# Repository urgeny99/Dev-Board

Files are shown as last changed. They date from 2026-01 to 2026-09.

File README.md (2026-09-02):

# This is a self made dev board that i can use on many different projects. For example mount it on a bread board and connect a small screen or something like that.
# Story
I made started this project without knowing almost anything about PCBs but with the time as i followed the tutrial more and more things got clear. I was not sure what to use this for but i started watching videos and and did research. It is actually a very cool project. I am not sure if it will be easy soldering at home but i like a challange so i'll try it.
I will probably be using this dev board with bread boards to try experimenting and i maybe order some more cool components to try out how they work. (e.g OLED screens, small sensors etc.)
## Parts
What this board has are:
- USB-C conmector
- 16Mb flash storage
- RP2040 "CPU"
- 12MHz Crystal Osillator
- Temperature sensor
- Small NeoPixel
- 20+ GPIO pins






## Based on @KaiTheJollyGuy’s tutorial on how to make a devboard

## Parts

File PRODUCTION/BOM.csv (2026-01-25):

Index | LCSC# | MPN | Manufacturer | Package | Customer # | Description | RoHS | Quantity | MOQ | Multiple | Unit Price($) | Extended Price($)
1 | C15849 | CL10A105KB8NNNC | Samsung Electro-Mechanics | 0603 |  | 1uF ±10% 50V Ceramic Capacitor X5R 0603 | yes | 50 | 50 | 50 | 0.0056 | 0.28
2 | C14663 | CC0603KRX7R9BB104 | YAGEO | 0603 |  | 100nF ±10% 50V Ceramic Capacitor X7R 0603 | yes | 200 | 100 | 100 | 0.0021 | 0.42
3 | C440198 | GRM21BR61H106KE43L | muRata | 0805 |  | 10uF ±10% 50V Ceramic Capacitor X5R 0805 | yes | 20 | 10 | 10 | 0.0628 | 1.26
4 | C1663 | CL10C330JB8NNNC | Samsung Electro-Mechanics | 0603 |  | 33pF ±5% 50V Ceramic Capacitor C0G 0603 | yes | 100 | 100 | 100 | 0.0043 | 0.43
5 | C19702 | CL10A106KP8NNNC | Samsung Electro-Mechanics | 0603 |  | 10uF ±10% 10V Ceramic Capacitor X5R 0603 | yes | 50 | 50 | 50 | 0.0065 | 0.33
6 | C5149201 | SK6812MINI-E | OPSCO Optoelectronics | SMD |  | SMD LED Addressable, Specialty RoHS | yes | 10 | 5 | 5 | 0.0874 | 0.87
7 | C165948 | TYPE-C-31-M-12 | Korean Hroparts Elec | SMD |  | USB-C (USB TYPE-C) Receptacle Connector 16 Position Surface Mount | yes | 10 | 5 | 5 | 0.1789 | 1.79
8 | C50981 | 2.54-1*20P | BOOMELE(Boom Precision Elec) | Through Hole,P=2.54mm |  | Pin Header 20 Position 2.54mm Pitch Single Row Through Hole -40℃~+105℃ | yes | 10 | 5 | 5 | 0.1157 | 1.16
9 | C24980 | 1.27-1*3P | BOOMELE(Boom Precision Elec) | Through Hole,P=1.27mm |  | Pin Header 3 Position 1.27mm Pitch Single Row Through Hole -55℃~+105℃ | yes | 20 | 20 | 20 | 0.0294 | 0.59
10 | C23186 | 0603WAF5101T5E | UNI-ROYAL | 0603 |  | 5.1kΩ ±1% 100mW 0603 Thick Film Resistor | yes | 100 | 100 | 100 | 0.0011 | 0.11
11 | C25190 | 0603WAF270JT5E | UNI-ROYAL | 0603 |  | 27Ω ±1% 100mW 0603 Thick Film Resistor | yes | 100 | 100 | 100 | 0.0012 | 0.12
12 | C21190 | 0603WAF1001T5E | UNI-ROYAL | 0603 |  | 1kΩ ±1% 100mW 0603 Thick Film Resistor | yes | 100 | 100 | 100 | 0.0012 | 0.12
13 | C25804 | 0603WAF1002T5E | UNI-ROYAL | 0603 |  | 10kΩ ±1% 100mW 0603 Thick Film Resistor | yes | 100 | 100 | 100 | 0.0011 | 0.11
14 | C22962 | 0603WAF2200T5E | UNI-ROYAL | 0603 |  | 220Ω ±1% 100mW 0603 Thick Film Resistor | yes | 100 | 100 | 100 | 0.0013 | 0.13
15 | C39051 | MCP1700T-3302E/TT | MICROCHIP | SOT-23 |  | 6V Positive Fixed 3.3V SOT-23 Voltage Regulators - Linear, Low Drop Out (LDO) Regulators RoHS | yes | 10 | 5 | 5 | 0.3617 | 3.62
16 | C28927 | TMP112AIDRLR | TI | SOT-563 |  | Temperature Sensor -40℃~+125℃ SOT-563 | yes | 10 | 5 | 5 | 0.2273 | 2.27
17 | C2843335 | W25Q16JVUXIQ | Winbond | USON-8-EP(2x3) |  | 2.7V~3.6V 16Mbit 133MHz SPI USON-8-EP(2x3) Memory (ICs) RoHS | yes | 8 | 4 | 4 | 1.1288 | 9.03
18 | C9002 | X322512MSB4SI | YXC Crystal Oscillators | SMD3225-4P |  | Crystal 12MHz ±10ppm 20pF SMD3225-4P | yes | 10 | 10 | 10 | 0.0688 | 0.69
19 | C2040 | RP2040 | Raspberry Pi | LQFN-56(7x7) |  | 133MHz 30 LQFN-56(7x7) Microcontrollers RoHS | yes | 10 | 1 | 1 | 0.8644 | 8.64
20 | C720477 | TS-1088-AR02016 | XUNPU | SMD,4x3mm |  | Tactile Switch SPST 160gf 2mm SMD (SMT) Tab 4mm x 3mm Surface Mount | yes | 10 | 10 | 10 | 0.0426 | 0.43
21 | C99782 | RC0603FR-074K7L | YAGEO | 0603 |  | 100mW 4.7kΩ 75V Thick Film Resistor ±100ppm/℃ ±1% 0603 Chip Resistor - Surface Mount RoHS | yes | 100 | 100 | 100 | 0.0013 | 0.13

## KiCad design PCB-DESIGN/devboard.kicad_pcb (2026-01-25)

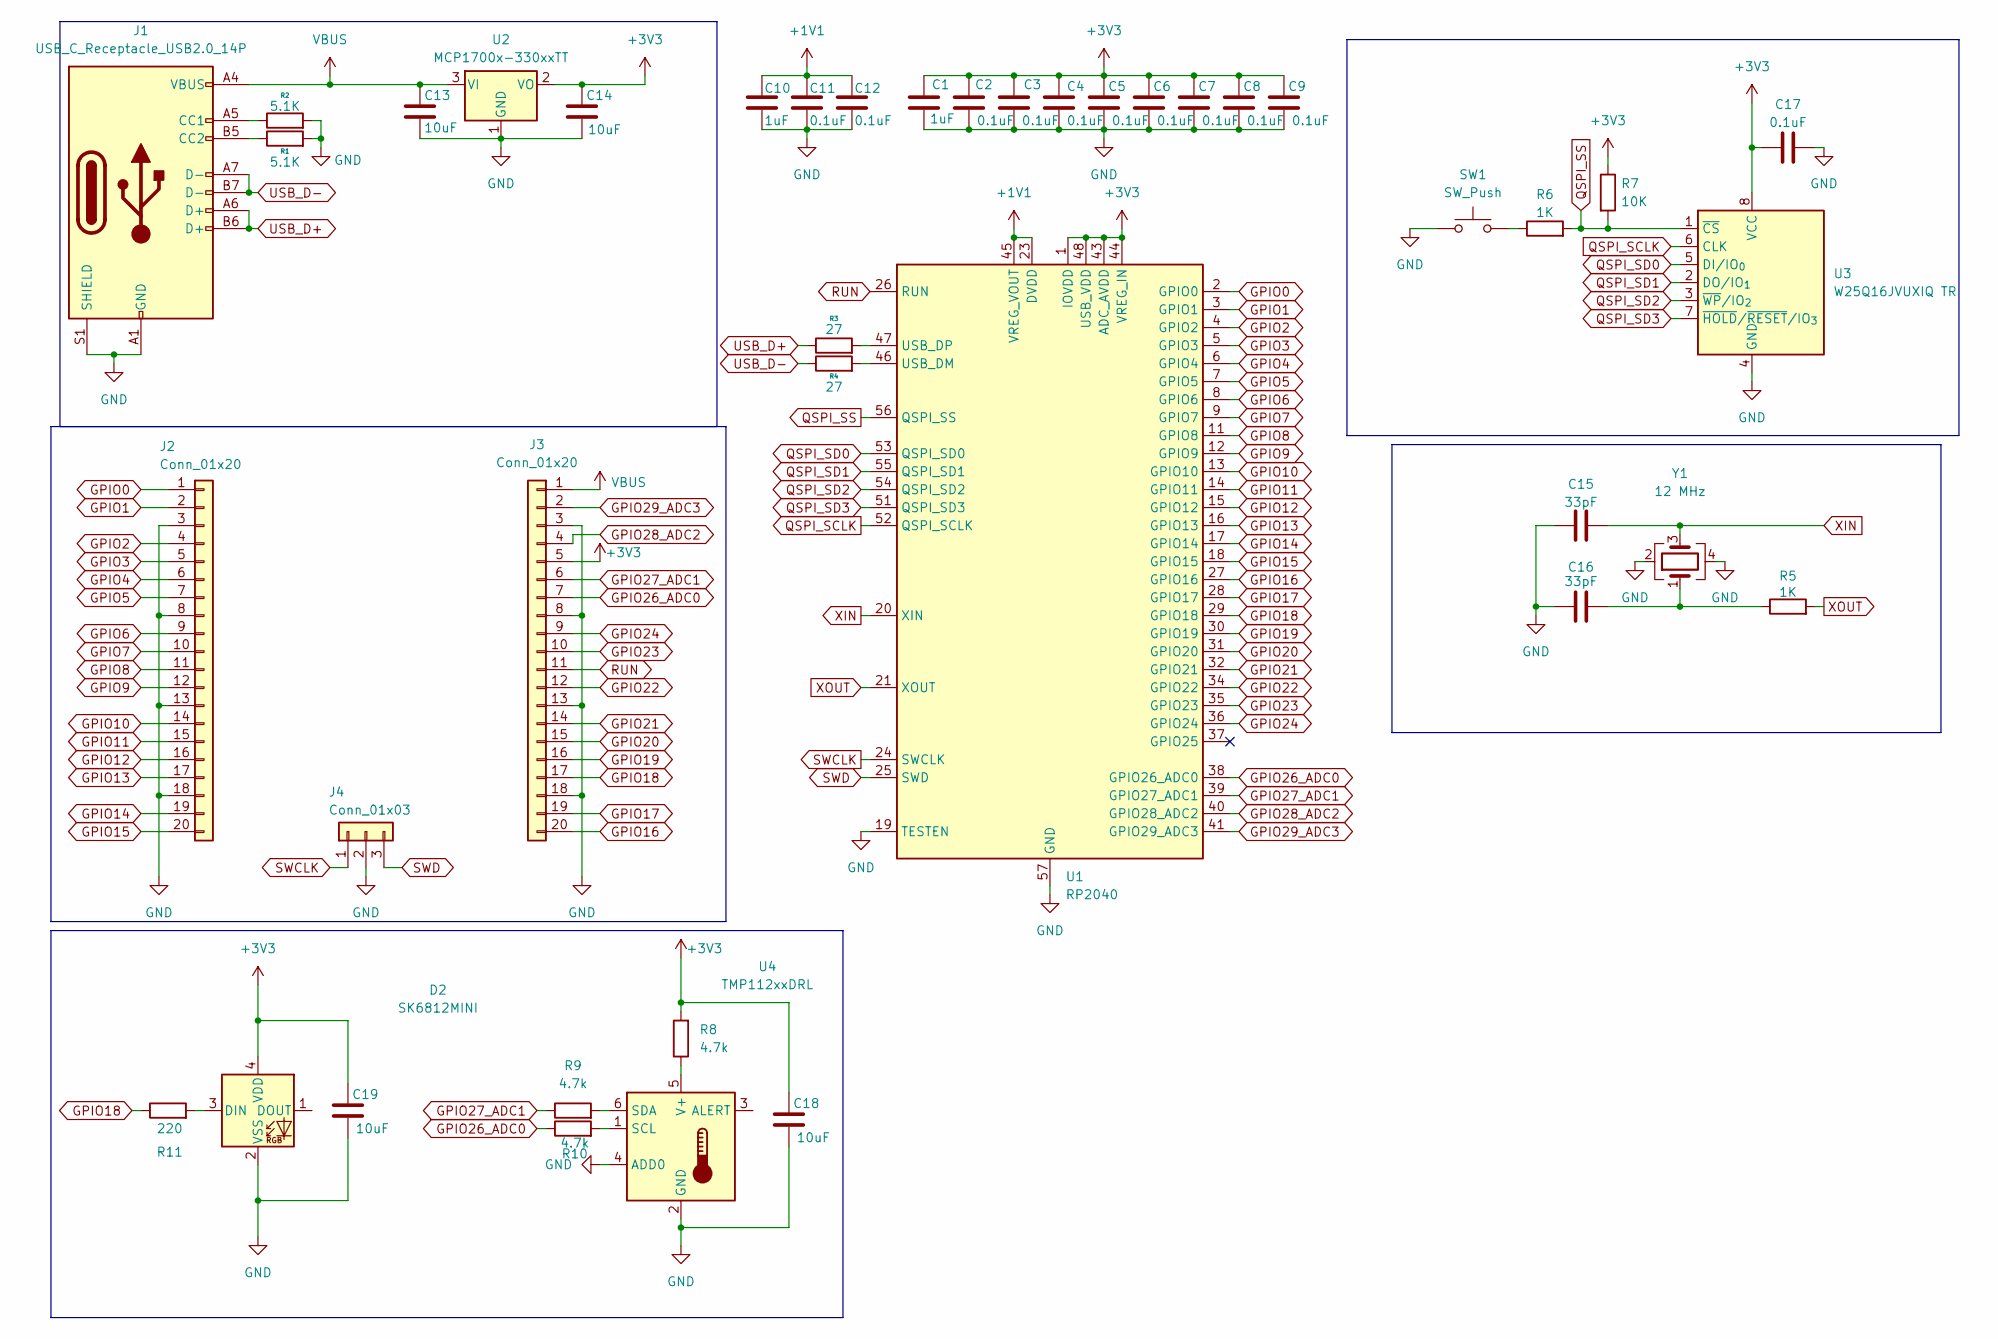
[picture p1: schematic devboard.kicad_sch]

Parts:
C1, C10: 1uF; C_0603_1608Metric
C2, C3, C4, C5, C6, C7, C8, C9, C11, C12, C17: 0.1uF; C_0603_1608Metric
C13, C14: 10uF; C_0805_2012Metric
C15, C16: 33pF; C_0603_1608Metric
C18, C19: 10uF; C_0603_1608Metric
D2: SK6812MINI; LED_SK6812MINI_PLCC4_3.5x3.5mm_P1.75mm
J1: USB_C_Receptacle_USB2.0_14P; USB_C_Receptacle_HRO_TYPE-C-31-M-12
J2, J3: Conn_01x20; PinHeader_1x20_P2.54mm_Vertical
J4: Conn_01x03; PinHeader_1x03_P2.54mm_Vertical
R1, R2: 5.1K; R_0603_1608Metric
R3, R4: 27; R_0603_1608Metric
R5, R6: 1K; R_0603_1608Metric
R7: 10K; R_0603_1608Metric
R8, R9, R10: 4.7k; R_0603_1608Metric
R11: 220; R_0603_1608Metric
SW1: SW_Push; SW_Push_SPST_NO_Alps_SKRK
U1: RP2040; QFN-56-1EP_7x7mm_P0.4mm_EP3.2x3.2mm
U2: MCP1700x-330xxTT; SOT-23
U3: W25Q16JVUXIQ TR; Winbond_USON-8-1EP_3x2mm_P0.5mm_EP0.2x1.6mm
U4: TMP112xxDRL; SOT-563
Y1: 12 MHz; Crystal_SMD_3225-4Pin_3.2x2.5mm

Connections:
+1V1: C10.1, C11.1, C12.1, U1.23 (DVDD), U1.45 (VREG_VOUT), U1.50 (DVDD)
+3V3: C1.1, C2.1, C3.1, C4.1, C5.1, C6.1, C7.1, C8.1, C9.1, C14.1, C17.1, C18.1, C19.1, D2.4 (VDD), J3.5, R7.1, R8.2, U1.1 (IOVDD), U1.10 (IOVDD), U1.22 (IOVDD), U1.33 (IOVDD), U1.42 (IOVDD), U1.43 (ADC_AVDD), U1.44 (VREG_IN), U1.48 (USB_VDD), U1.49 (IOVDD), U2.2 (VO), U3.8 (VCC)
GND: C1.2, C2.2, C3.2, C4.2, C5.2, C6.2, C7.2, C8.2, C9.2, C10.2, C11.2, C12.2, C13.2, C14.2, C15.1, C16.1, C17.2, C18.2, C19.2, D2.2 (VSS), J1.A1 (GND), J1.A12 (GND), J1.B1 (GND), J1.B12 (GND), J1.S1 (SHIELD), J2.3, J2.8, J2.13, J2.18, J3.3, J3.8, J3.13, J3.18, J4.2, R1.2, R2.2, SW1.1, U1.19 (TESTEN), U1.57 (GND), U2.1 (GND), U3.4 (GND), U4.2 (GND), U4.4 (ADD0), Y1.2, Y1.4
GPIO0: J2.1, U1.2 (GPIO0)
GPIO1: J2.2, U1.3 (GPIO1)
GPIO2: J2.4, U1.4 (GPIO2)
GPIO3: J2.5, U1.5 (GPIO3)
GPIO4: J2.6, U1.6 (GPIO4)
GPIO5: J2.7, U1.7 (GPIO5)
GPIO6: J2.9, U1.8 (GPIO6)
GPIO7: J2.10, U1.9 (GPIO7)
GPIO8: J2.11, U1.11 (GPIO8)
GPIO9: J2.12, U1.12 (GPIO9)
GPIO10: J2.14, U1.13 (GPIO10)
GPIO11: J2.15, U1.14 (GPIO11)
GPIO12: J2.16, U1.15 (GPIO12)
GPIO13: J2.17, U1.16 (GPIO13)
GPIO14: J2.19, U1.17 (GPIO14)
GPIO15: J2.20, U1.18 (GPIO15)
GPIO16: J3.20, U1.27 (GPIO16)
GPIO17: J3.19, U1.28 (GPIO17)
GPIO18: J3.17, R11.1, U1.29 (GPIO18)
GPIO19: J3.16, U1.30 (GPIO19)
GPIO20: J3.15, U1.31 (GPIO20)
GPIO21: J3.14, U1.32 (GPIO21)
GPIO22: J3.12, U1.34 (GPIO22)
GPIO23: J3.10, U1.35 (GPIO23)
GPIO24: J3.9, U1.36 (GPIO24)
GPIO26_ADC0: J3.7, R10.1, U1.38 (GPIO26_ADC0)
GPIO27_ADC1: J3.6, R9.1, U1.39 (GPIO27_ADC1)
GPIO28_ADC2: J3.4, U1.40 (GPIO28_ADC2)
GPIO29_ADC3: J3.2, U1.41 (GPIO29_ADC3)
unnamed: C16.2, R5.1, Y1.1
unnamed: D2.3 (DIN), R11.2
unnamed: J1.A5 (CC1), R2.1
unnamed: J1.B5 (CC2), R1.1
unnamed: R6.1, SW1.2
unnamed: R4.2, U1.46 (USB_DM)
unnamed: R3.2, U1.47 (USB_DP)
unnamed: R10.2, U4.1 (SCL)
unnamed: R9.2, U4.6 (SDA)
unnamed: R8.1, U4.5 (V+)
QSPI_SCLK: U1.52 (QSPI_SCLK), U3.6 (CLK)
QSPI_SD0: U1.53 (QSPI_SD0), U3.5 (DI/IO_{0})
QSPI_SD1: U1.55 (QSPI_SD1), U3.2 (DO/IO_{1})
QSPI_SD2: U1.54 (QSPI_SD2), U3.3 (~WP/IO_{2})
QSPI_SD3: U1.51 (QSPI_SD3), U3.7 (~HOLD/~RESET/IO_{3})
QSPI_SS: R6.2, R7.2, U1.56 (QSPI_SS), U3.1 (~CS)
RUN: J3.11, U1.26 (RUN)
SWCLK: J4.1, U1.24 (SWCLK)
SWD: J4.3, U1.25 (SWD)
USB_D+: J1.A6 (D+), J1.B6 (D+), R3.1
USB_D-: J1.A7 (D-), J1.B7 (D-), R4.1
VBUS: C13.1, J1.A4 (VBUS), J1.A9 (VBUS), J1.B4 (VBUS), J1.B9 (VBUS), J3.1, U2.3 (VI)
XIN: C15.2, U1.20 (XIN), Y1.3
XOUT: R5.2, U1.21 (XOUT)

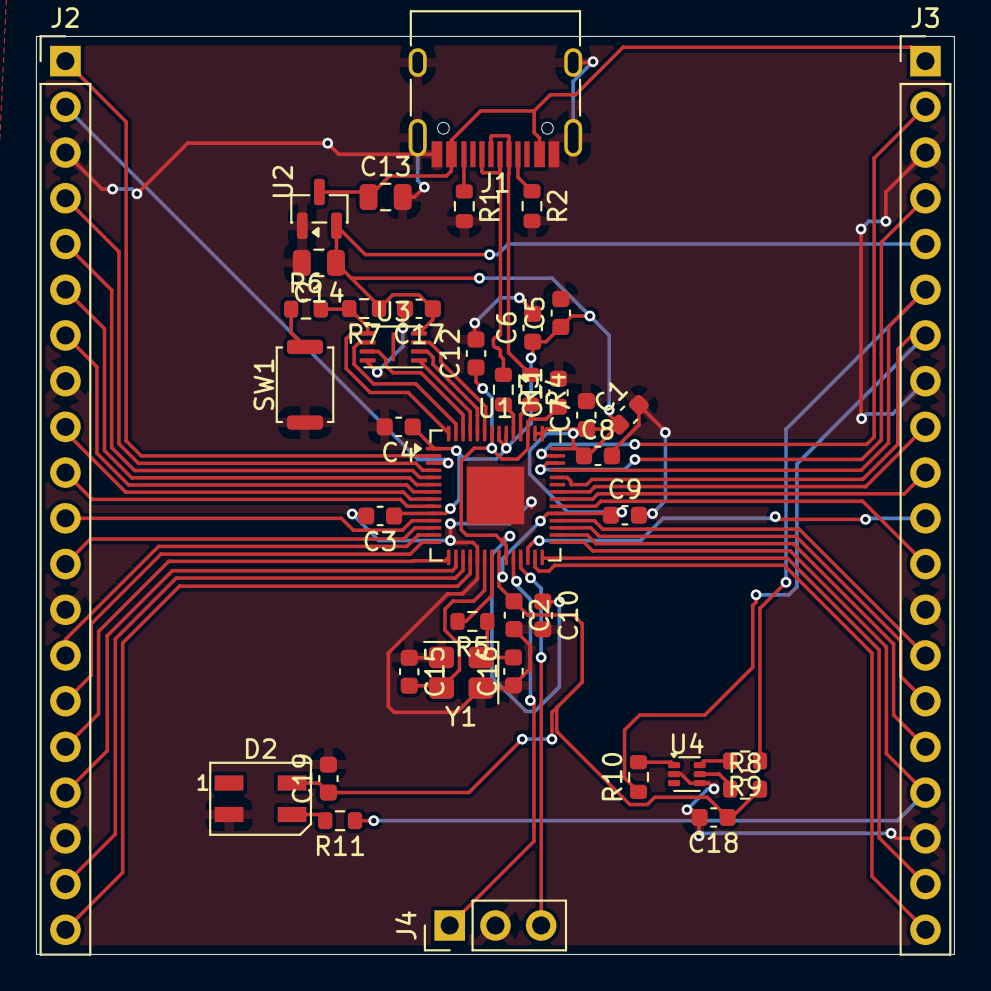
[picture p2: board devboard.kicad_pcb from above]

Board: 2 copper layers, 51.0 x 51.0 mm, 41 parts (0 on the bottom side), 56 nets.
